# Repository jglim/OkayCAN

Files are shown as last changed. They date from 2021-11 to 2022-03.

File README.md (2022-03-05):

# OkayCAN

*The okayest ESP32-S2 CAN development board*

Expectations shield

OkayCAN board

## Features

- Essentially an ESP32-S2 with a CAN transceiver and supporting components.
- Native USB support, saving on an additional USB-UART chip.
- Designed to fit a commonly available OBD enclosure and its 16-pin connectors.
- Each board should cost about US$10 each when assembling about 10 boards, making it fairly affordable in small runs.
- Easy to assemble/manufacture, as all components are on a single side, and most components are surface mounted.
- Uses a USB-C connector, which is easier to interface when the device is installed in difficult-to-reach places.

### Free

This project is permissively licensed (MIT)

- No restrictions and no royalties on private / commercial use.
- The design files (schematic, board) can be downloaded and modified to fit your own requirements.
- Ready-to-use manufacturing files (gerbers, BOM) are also available. Send it to your preferred fab to have the boards made.
- Please feel free to sell the boards that you have made, even if it is a 1:1 clone. There is no need for attribution too.
- The selected [iso-tp stack](https://github.com/lishen2/isotp-c) from [lishen2](https://github.com/lishen2/) that is included in the examples is also MIT-licensed.

---

## Get an OkayCAN

**Build it yourself**

- PCB: [Gerbers are zipped](https://github.com/jglim/OkayCAN/raw/main/Hardware/V1.1/OkayCAN/gerbers/OkayCAN_fab_gerbers_211101.zip) and ready to be uploaded to your fab
- BOM: Almost every component has a matching LCSC part number, and [the CSV](https://github.com/jglim/OkayCAN/blob/main/Hardware/V1.0/OkayCAN/raster/OkayCAN_BOM.csv) works with their BOM upload feature.
    - The only odd part is the OBD2 header (with case), which has to be sourced from marketplaces like Aliexpress
- Assembly: as most of the parts are surface-mounted, getting a stencil will make the process much quicker.

**Buy one**

I'm not assembling any for sale at this time, though I would love to see it being accessible to more people. If you decide to sell complete boards, please let me know so that I may be able to share about it. Everyone is welcome to create and sell clones/variants of the OkayCAN.

---

## Firmware

**[OkayCAN_GettingStarted](https://github.com/jglim/OkayCAN/tree/main/Firmware/Examples/OkayCAN_GettingStarted)**

Get started quickly with this example, which queries a (MB) ECU for parameters such as VIN, part number, and software versions, then displays it on the serial port.

The example will demonstrate communications with an ECU over UDS (a layer above CAN), as well as usage of the serial port over USB CDC. When working properly, the serial should show an output similar to this:

```
Voltage: 11993 mV
00000BBE TX ISO-TP: 22 F1 8C
00000BC3 RX ISO-TP: 62 F1 8C 33 31 33 31 XX XX XX XX
Received Serial Number: 3131XXXX
Voltage: 11979 mV
00000FA7 TX ISO-TP: 22 F1 90
00000FAC RX ISO-TP: 62 F1 90 57 44 44 32 34 36 32 30 30 31 4A XX XX XX XX XX XX
Received VIN Original: WDD2462001JXXXXXX
Voltage: 12003 mV
00001390 TX ISO-TP: 22 F1 A0
00001394 RX ISO-TP: 62 F1 A0 57 44 44 32 34 36 32 30 30 31 4A XX XX XX XX XX XX
Received VIN Current: WDD2462001JXXXXXX
Voltage: 12003 mV
00001779 TX ISO-TP: 22 F1 21
00001783 RX ISO-TP: 62 F1 21 36 35 31 39 30 34 30 33 30 31 36 35 31 39 30 32 33 31 30 31 36 35 31 39 30 33 31 34 33 31
Received Software block data:
6519040301
6519023101
6519031431
Voltage: 11984 mV
00001B62 TX ISO-TP: 22 F1 00
00001B67 RX ISO-TP: 62 F1 00 02 21 31 01
Received Variant ID: 2131
Voltage: 12003 mV
00001F4B TX ISO-TP: 22 F1 11
00001F50 RX ISO-TP: 62 F1 11 36 35 31 39 30 31 30 36 30 31
Received Part Number: 6519010601
...
```

**[OkayCAN_OBD](https://github.com/jglim/OkayCAN/tree/main/Firmware/Examples/OkayCAN_OBD)**

_UNVERIFIED: No vehicle to test on; tested against a simulated ecu on another esp32. Please let me know if this works! --jg_

Queries an OBD-II compliant ECU for its engine speed, vehicle speed, and throttle position. These parameters are typically supported by most ECUs.

A open Wi-Fi network with the name "OkayCAN-OBD" is also created, and serves a simple web page over http at [192.168.4.1](http://192.168.4.1/) . The page shows real-time results of the OBD queries as JSON if they are available.

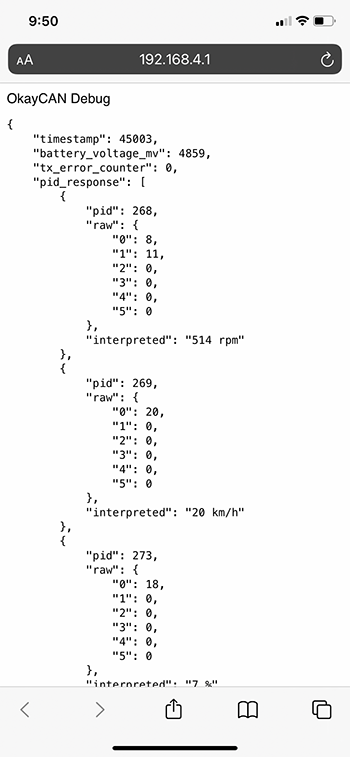
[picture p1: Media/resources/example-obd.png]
OBD Example screenshot


---

## Hardware

⚠️ Warning: components are rated for 12V only! Please do not connect to 24V systems.

### OkayCAN V1.0

*Please use the newer V1.1 as it addresses a board outline issue*

**Schematic [(PDF)](https://github.com/jglim/OkayCAN/blob/main/Hardware/V1.0/OkayCAN/raster/OkayCAN_Schematic.pdf)**

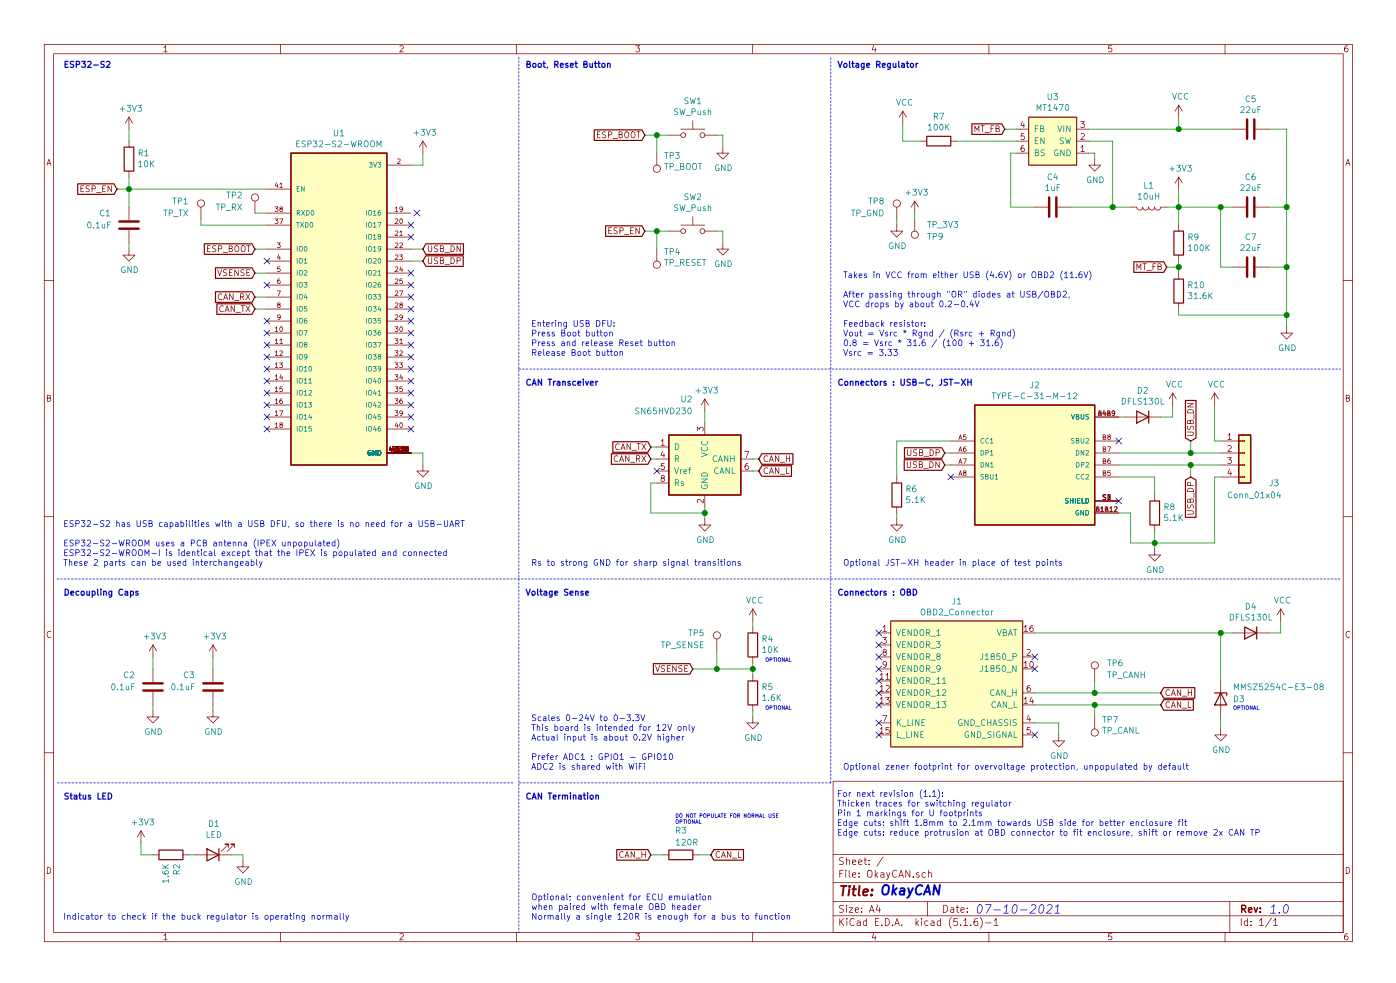
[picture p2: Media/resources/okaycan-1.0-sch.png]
OkayCAN schematic


TL;DR:
**Power**: Vin (USB: 5V, OBD: 12V) with a diode "OR" into a 3.3V buck regulator (MT1470).
**uC**: CAN_TX @ GPIO5, CAN_RX @ GPIO4, VSENSE @ GPIO2 (Divider ratio: Vin-10K,1.6K-GND)
**OBD**: Only CAN TX/RX, VBATT and *chassis* GND are connected. Other pins are NC.

⚠️ The MT1470 regulator only starts operating at 4.5V, which leaves a small margin for the schottky's forward voltage when running off 5V from USB.

ℹ️ The optional 120R CAN resistors should **not** be populated for normal operation as the bus on the vehicle's port normally includes termination resistors.

ℹ️ Test points are available on the back. The ESP32-S2 can also be flashed with an external USB-UART with these test points (like the regular ESP32).

**Board**

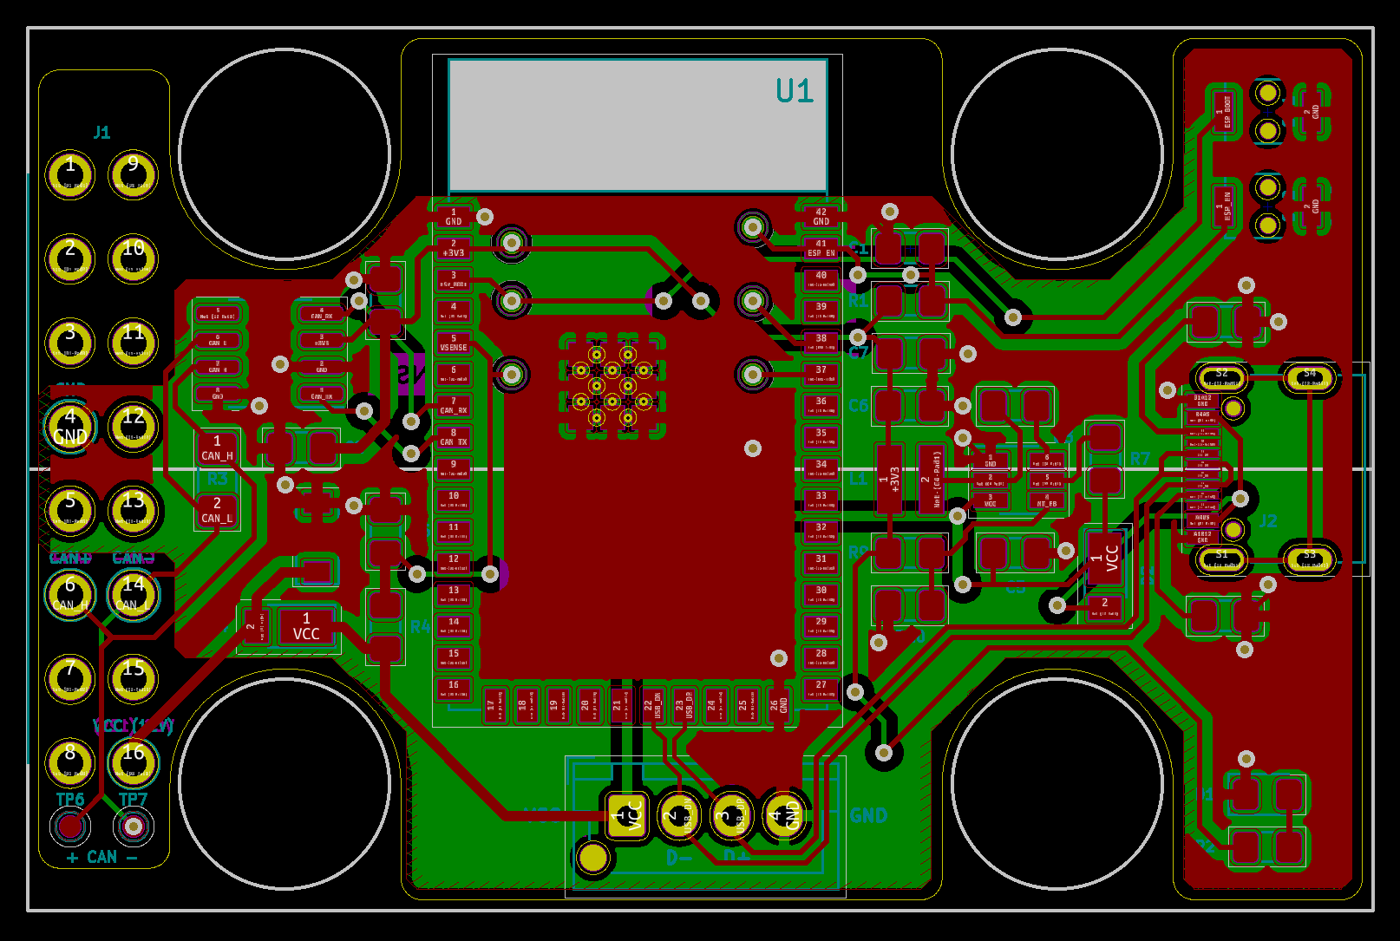
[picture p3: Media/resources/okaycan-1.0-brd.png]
OkayCAN board


ℹ️ V1.0 requires a minor case modification to fit properly, as the OBD connector's sides are too wide. There are two small plastic tabs on the case, near the OBD header which can be safely removed to allow the board to fit properly.

**BOM**

Available [here](https://github.com/jglim/OkayCAN/blob/main/Hardware/V1.0/OkayCAN/raster/OkayCAN_BOM.csv). Budgetary component prices available in [this extended BOM](https://github.com/jglim/OkayCAN/blob/main/Hardware/V1.0/OkayCAN/raster/OkayCAN_Price_Breakdown.csv).

---

### OkayCAN V1.1

*Latest version*

Minor revision to V1.0

- Adjusted board outline to fit the standard cases without modifications
- Added an optional user LED to GPIO16, unpopulated by default
- Minor routing improvements, footprint positions are unchanged and a stencil from V1.0 will still work on this board

---

## DFU

The ESP32-S2 has a USB ROM bootloader which is read-only. This guarantees that a faulty firmware will not brick the device.
OkayCAN includes BOOT and RESET buttons which can be used to bring the device into DFU, to upload a new firmware.

*Enter DFU mode with these steps:*

1. Press BOOT button
2. Press RESET button
3. Release RESET button
4. Release BOOT button

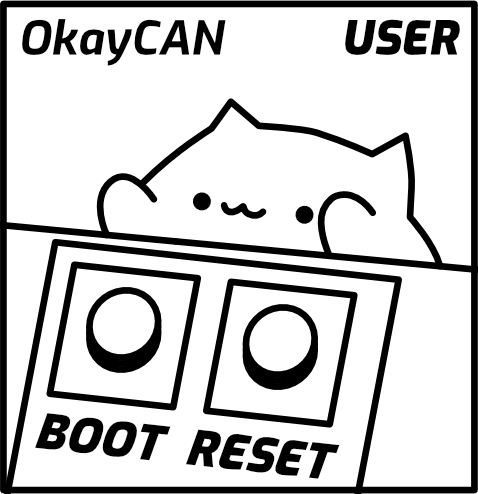
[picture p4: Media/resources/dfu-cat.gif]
Animated DFU instructions


The device can also be put into DFU mode using only the BOOT button. Hold down BOOT while disconnecting and reconnecting the USB cable, then release BOOT.

After flashing the firmware, remember to press RESET once, or reconnect the USB cable to exit DFU and start running your firmware.

---

## Contributing

Please..

- Build cool stuff with the OkayCAN (and let me know if you do, too!).
- Point out and suggest fixes if there are any issues with the hardware design or firmware.
- Add or improve on the existing examples.
- If you fab these boards with a pick-and-place, I would love to hear about your experience.

Need ideas on what to build? Here are some ideas:

- Control an instrument cluster for your racing or truck sim.
- A vehicle communications interface e.g. a J2534 interface.
- Wireless coding/tuning/upgrading via your phone
- Race telemetry/logger with digital gauges

---

## License

MIT

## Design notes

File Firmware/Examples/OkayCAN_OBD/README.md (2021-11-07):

# OkayCAN : OBD

**UNVERIFIED**
_No vehicle to test on; tested against a simulated ecu on another esp32.
Please let me know if this works! --jg_

Queries an OBD-II compliant ECU for its engine speed, vehicle speed, 
and throttle position. These parameters are typically supported by most ECUs.

A open Wi-Fi network with the name "OkayCAN-OBD" is also created, and serves a 
simple web page over http at 192.168.4.1 . The page shows real-time results of the
OBD queries as JSON if they are available.

The contents of the web page can be found in the index.html
Further instructions on editing it can be found in mainpage.h

Assumes that the bus arbitration IDs are 7E0/7E8, running at 500k baud. 
These values can be changed in config.h

This example depends on [ESPAsyncTCP](https://github.com/me-no-dev/ESPAsyncTCP) and [ESPAsyncWebServer](https://github.com/me-no-dev/ESPAsyncWebServer) from [me-no-dev](https://github.com/me-no-dev/).

## Uploading

Enter DFU mode with these steps:

1. Press BOOT button
2. Press RESET button
3. Release RESET button
4. Release BOOT button

When done correctly, a serial port should appear on the connected computer, which can be used for uploading the firmware.
After the upload completes, press and release RESET to begin running the newly flashed firmware.

## Webpage Output

```
OkayCAN Debug
{
    "timestamp": 35530765,
    "battery_voltage_mv": 4783,
    "tx_error_counter": 0,
    "pid_response": [
        {
            "pid": 268,
            "raw": {
                "0": 1,
                "1": 224,
                "2": 0,
                "3": 0,
                "4": 0,
                "5": 0
            },
            "interpreted": "120 rpm"
        },
        {
            "pid": 269,
            "raw": {
                "0": 231,
                "1": 0,
                "2": 0,
                "3": 0,
                "4": 0,
                "5": 0
            },
            "interpreted": "231 km/h"
        },
        {
            "pid": 273,
            "raw": {
                "0": 229,
                "1": 0,
                "2": 0,
                "3": 0,
                "4": 0,
                "5": 0
            },
            "interpreted": "90 %"
        }
    ]
}
```

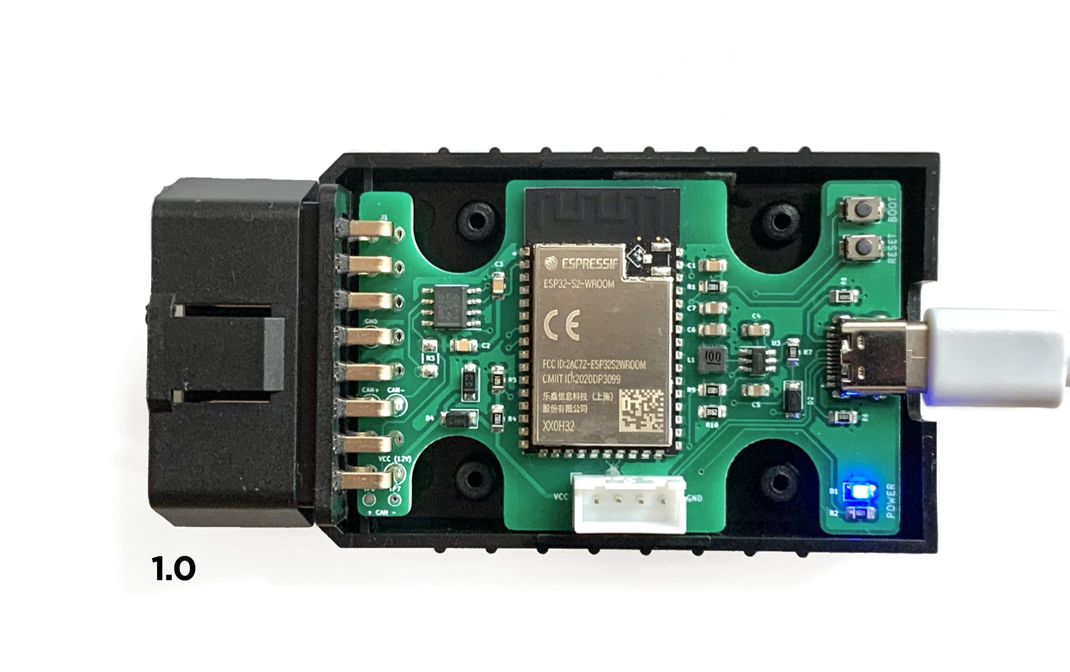
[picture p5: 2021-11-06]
Media/resources/okaycan.jpg

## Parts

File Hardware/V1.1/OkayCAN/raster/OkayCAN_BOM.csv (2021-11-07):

Id | Designator | Package | Quantity | Designation | Supplier and ref
1 | R11,R5,R2 | R_0805_2012Metric_Pad1.15x1.40mm_HandSolder | 3 | 1.6K
2 | D5,D1 | LED_0805_2012Metric_Pad1.15x1.40mm_HandSolder | 2 | LED
3 | G*** | OkayCAN_Silk | 1 | LOGO
4 | kibuzzard-615D3B2E,kibuzzard-615D34D3,kibuzzard-615D3669,kibuzzard-615D361C,kibuzzard-615D34DF,kibuzzard-615D34D3,kibuzzard-615D34C8,kibuzzard-615D34B9,kibuzzard-615D34B0,kibuzzard-615D34A6 | label | 10 | G***
5 | TP9 | TestPoint_Pad_D1.0mm | 1 | TP_3V3
6 | TP8 | TestPoint_Pad_D1.0mm | 1 | TP_GND
7 | TP4 | TestPoint_Pad_D1.0mm | 1 | TP_RESET
8 | TP3 | TestPoint_Pad_D1.0mm | 1 | TP_BOOT
9 | TP7 | TestPoint_Pad_D1.0mm | 1 | TP_CANL
10 | TP6 | TestPoint_Pad_D1.0mm | 1 | TP_CANH
11 | TP5 | TestPoint_Pad_D1.0mm | 1 | TP_SENSE
12 | TP2 | TestPoint_Pad_D1.0mm | 1 | TP_RX
13 | TP1 | TestPoint_Pad_D1.0mm | 1 | TP_TX
14 | U3 | SOT-23-6_Handsoldering | 1 | MT1470
15 | U2 | SOIC-8_3.9x4.9mm_P1.27mm | 1 | SN65HVD230
16 | U1 | XCVR_ESP32-S2-WROOM | 1 | ESP32-S2-WROOM
17 | SW2,SW1 | HRO-K2-1807 | 2 | SW_Push
18 | R10 | R_0805_2012Metric_Pad1.15x1.40mm_HandSolder | 1 | 31.6K
19 | R9,R7 | R_0805_2012Metric_Pad1.15x1.40mm_HandSolder | 2 | 100K
20 | R8,R6 | R_0805_2012Metric_Pad1.15x1.40mm_HandSolder | 2 | 5.1K
21 | R4,R1 | R_0805_2012Metric_Pad1.15x1.40mm_HandSolder | 2 | 10K
22 | R3 | R_1206_3216Metric_Pad1.42x1.75mm_HandSolder | 1 | 120R
23 | L1 | CHILSIN-LVF303012 | 1 | 10uH
24 | J3 | JST_XH_B4B-XH-AM_1x04_P2.50mm_Vertical | 1 | Conn_01x04
25 | J2 | HRO_TYPE-C-31-M-12 | 1 | TYPE-C-31-M-12
26 | J1 | OBD-Male | 1 | OBD2_Connector
27 | D4,D2 | D_PowerDI-123 | 2 | DFLS130L
28 | D3 | D_SOD-123 | 1 | MMSZ5254C-E3-08
29 | C7,C6,C5 | C_0805_2012Metric_Pad1.15x1.40mm_HandSolder | 3 | 22uF
30 | C4 | C_0805_2012Metric_Pad1.15x1.40mm_HandSolder | 1 | 1uF
31 | C3,C2,C1 | C_0805_2012Metric_Pad1.15x1.40mm_HandSolder | 3 | 0.1uF

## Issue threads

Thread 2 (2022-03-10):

WebBLE

brandonros, 2022-03-10:
https://github.com/bri3d/esp32-isotp-ble-bridge

You should make it compatible with this firmware.

brandonros, 2022-03-10:
You only support WiFi, forogt.

jglim, 2022-03-11:
Yes, unfortunately the esp32-s2 does not appear to be capable of BLE too.

https://www.espressif.com/sites/default/files/documentation/esp32-s2_datasheet_en.pdf
https://www.adafruit.com/product/4653

_".. Also, thee is no Bluetooth support. However, we are super excited about the ESP32-S2's native USB which unlocks a lot of capabilities for advanced interfacing!"_

brandonros, 2022-03-11:
Which ESP32 chip has BLE?

brandonros, 2022-03-11:
which does macchina a0 use? you should update your schematic to use that. bigger market for BLE than USB in my opinion.

i’m not a fan of flashing cars wirelessly on a $1 piece of silicon but hey…

jglim, 2022-03-11:
Looks like a regular esp32 (ESP32-WROVER-E)
https://github.com/macchina/a0-hardware/blob/master/A0%20Schematic%20Production.pdf

I'll keep your feedback in mind about the esp32 and BLE if the board is redesigned.

Closed 2022-03-10.

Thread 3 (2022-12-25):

Send consecutive frame

Liu-jingyu-CN, 2022-12-25:
Thanks a lot for this project, I have successfully try to read gateway.
But when I need to do more in-depth operations, I need to Send consecutive frame.
Perform other service operations by informing the gateway diagnostic instrument to access.
For example, use 2E service to send a piece of RAW CAN data to modify vehicle data.
Is it possible to add a demo that Send consecutive frame ？

00007937 TX ISO-TP: 22 F1 97
0000794B RX ISO-TP: 62 F1 97 47 57 20 4D 51 42 20 54 54 33 20 20 20
Received VW System Name: GW MQB TT3
00007D20 TX ISO-TP: 22 F1 91
00007D3D RX ISO-TP: 62 F1 91 38 53 30 39 30 37 34 36 38 46 20
Received VW ECU Hardware Number: 8S0907468F
00008109 TX ISO-TP: 22 F1 87
00008125 RX ISO-TP: 62 F1 87 38 53 30 39 30 37 34 36 38 4E 20
Received VW_Spare Part Number: 8S0907468N
000084F2 TX ISO-TP: 22 F1 A3
000084F9 RX ISO-TP: 62 F1 A3 30 32 34
Received Hardware Version Number: 024
000088DB TX ISO-TP: 22 F1 89
000088E1 RX ISO-TP: 62 F1 89 30 35 30 32
Received Software Version Number: 0502
00008CC4 TX ISO-TP: 22 F1 9E
00008CE7 RX ISO-TP: 62 F1 9E 45 56 5F 47 61 74 65 77 43 6F 6E 74 69 41 55 33 33 58 00
Received ASAM ODX File Identifier: EV_GatewContiAU33X
000090AD TX ISO-TP: 22 F1 A2
000090BB RX ISO-TP: 62 F1 A2 30 31 33 30 32 36
Received ASAM ODX File Version: 013026
00009496 TX ISO-TP: 22 06 00
000094C1 RX ISO-TP: 62 06 00 03 01 00 04 3F 08 59 00 5B 00 00 4A 1A 0B 00 00 00 01 01 00 00 00 00 00 00 00 00 00 00 00
Received VW Coding Value: 03 01 00 04 3F 08 59 00 5B 00 00 4A 1A 0B 00 00 00 01 01 00 00 00 00 00 00 00 00 00 00 00
0000987F TX ISO-TP: 22 04 90
000099FD RX ISO-TP: 62 04 90 21 2D 2D 2D 2D 2D 2D 2D 2D 2D 2D 2D 2D 2D 3A 2D 2D 2A 2D 2D 2E 2D 2A 2D 2D 2A 2D 2D 2D 2D 2D 2A 2A 2A 1A 2D 2D 2D 2D 2D 2D 2D 2D 2D 2D 2D 2D 2D 3A 2D 2D 2A 2D 2D 2E 2D 2A 2D 2D 2A 2A 1A 2D 2D 2D 2D 2D 2D 2D 2D 2D 2D 2D 2D 2D 3A 2D 2D 2A 2D 2D 2E 2D 2A 2D 2D 2A 2A 21 2D 2D 2D 2D 2D 2D 2D 2D 2D 2D 2D 2D 2D 3A 2D 2D 2A 2D 2D 2E 2D 2A 2D 2D 2A 2D 2D 2D 2D 2D 2A 2A 2A 1A 2D 2D 2D 2D 2D 2D 2D 2D 2D 2D 2D 2D 2D 3A 2D 2D 2A 2D 2D 2E 2D 2A 2D 2D 2A 2A 1A 2D 2D 2D 2D 2D 2D 2D 2D 2D 2D 2D 2D 2D 3A 2D 2D 2A 2D 2D 2E 2D 2A 2D 2D 2A 2A 21 2D 2D 2D 2D 2D 2D 2D 2D 2D 2D 2D 2D 2D 3A 2D 2D 2A 2D 2D 2E 2D 2A 2D 2D 2A 2D 2D 2D 2D 2D 2A 2A 2A 1A 2D 2D 2D 2D 2D 2D 2D 2D 2D 2D 2D 2D 2D 3A 2D 2D 2A 2D 2D 2E 2D 2A 2D 2D 2A 2A 1A 2D 2D 2D 2D 2D 2D 2D 2D 2D 2D 2D 2D 2D 3A 2D 2D 2A 2D 2D 2E 2D 2A 2D 2D 2A 2A
Received Battery Historical Data:
!-------------:--*--.-*--*-----***␚-------------:--*--.-*--**␚-------------:--*--.-*--**
!-------------:--*--.-*--*-----***␚-------------:--*--.-*--**␚-------------:--*--.-*--**
!-------------:--*--.-*--*-----***␚-------------:--*--.-*--**␚-------------:--*--.-*--**
00009C68 TX ISO-TP: 22 2A 26
00009C9B RX ISO-TP: 62 2A 26 01 00 00 00 00 00 00 00 00 00 00 00 00 00 00 00 00 00 00 00 00 00 00 00 00 00 00 00 00 00 00 00
Gateway Component List allocation: 01 00 00 00 00 00 00 00 00 00 00 00 00 00 00 00 00 00 00 00 00 00 00 00 00 00 00 00 00 00 00 00

jglim, 2022-12-28:
Hello,

Thanks for trying out the project. The included examples are supported by https://github.com/lishen2/isotp-c/ , which should support automatic frame segmentation.

In the below example, the buffer in `transport_tx_buffer` can be filled with more content (remember to change `content_length` too), and it should be automatically be broken into first/consecutive frames during transmission.

https://github.com/jglim/OkayCAN/blob/24859feef76e1b3540869f00db903b38f7d8b79d/Firmware/Examples/OkayCAN_GettingStarted/src/main.cpp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

Closed 2022-12-29.

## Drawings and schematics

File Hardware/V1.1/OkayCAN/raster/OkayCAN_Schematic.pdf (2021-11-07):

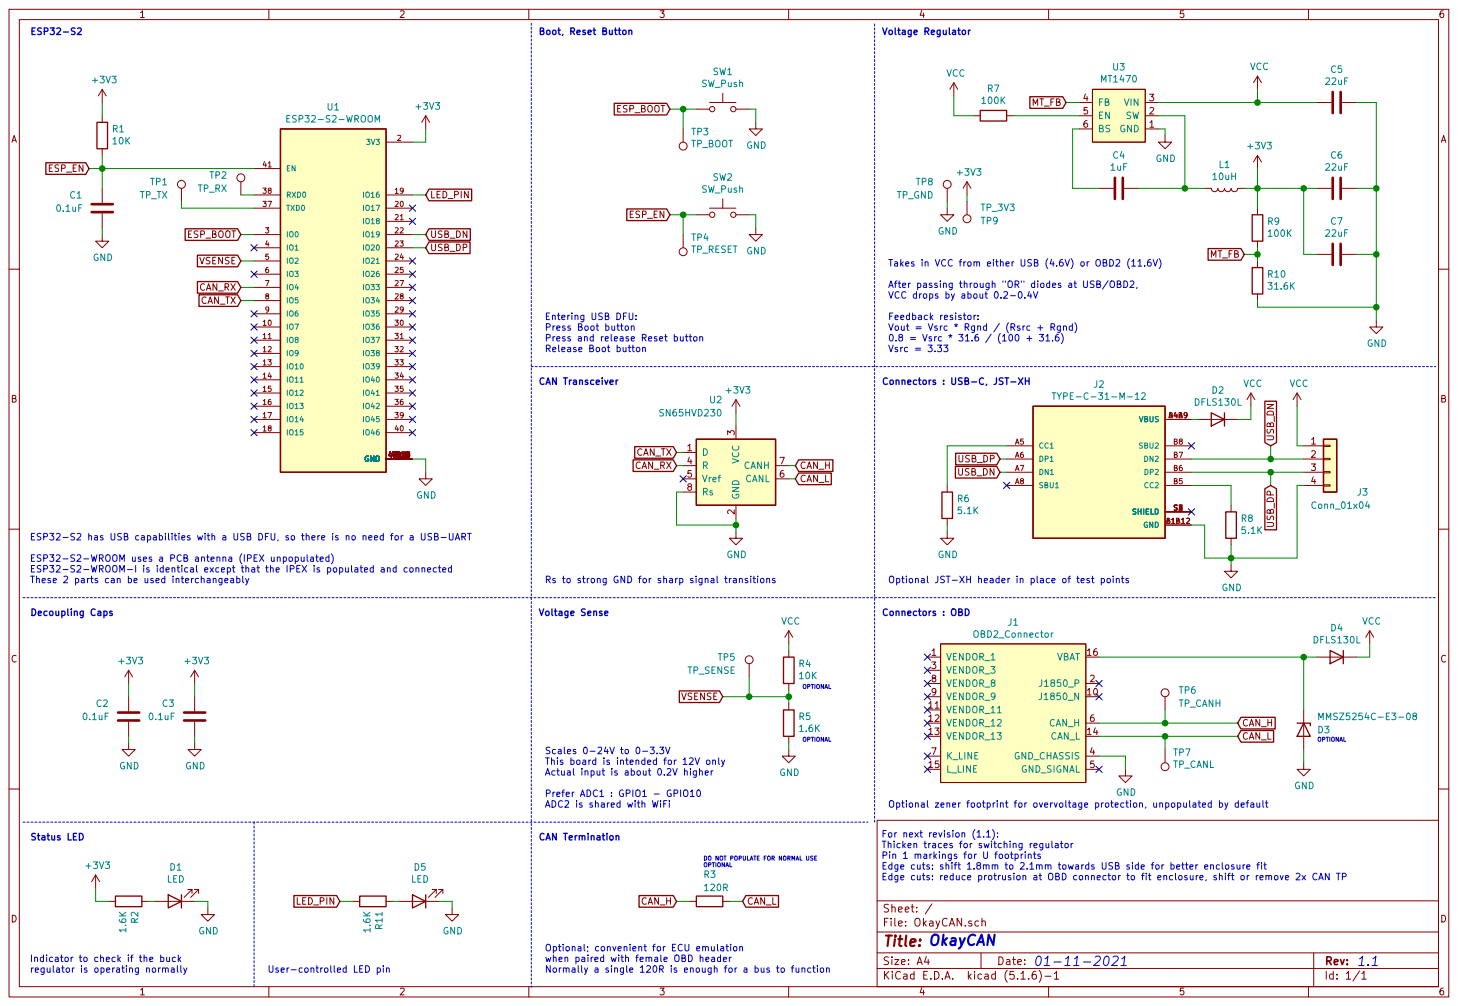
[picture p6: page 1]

Boot, Reset Button Entering USB DFU: Press Boot button Press and release Reset button Release Boot button Decoupling Caps

Takes in VCC from either USB (4.6V) or OBD2 (11.6V)

After passing through "OR" diodes at USB/OBD2,
VCC drops by about 0.2-0.4V

Feedback resistor: Vout = Vsrc * Rgnd / (Rsrc + Rgnd)

Connectors : USB-C, JST-XH

ESP32-S2 has USB capabilities with a USB DFU, so there is no need for a USB-UART

ESP32-S2-WROOM uses a PCB antenna (IPEX unpopulated)
ESP32-S2-WROOM-I is identical except that the IPEX is populated and connected
These 2 parts can be used interchangeably

Voltage Sense Scales 0-24V to 0-3.3V

This board is intended for 12V only
Actual input is about 0.2V higher Prefer ADC1 : GPIO1 - GPIO10 ADC2 is shared with WiFi

Thicken traces for switching regulator
Pin 1 markings for U footprints
Edge cuts: shift 1.8mm to 2.1mm towards USB side for better enclosure fit
Edge cuts: reduce protrusion at OBD connector to fit enclosure, shift or remove 2x CAN TP

Indicator to check if the buck regulator is operating normally

when paired with female OBD header
Normally a single 120R is enough for a bus to function

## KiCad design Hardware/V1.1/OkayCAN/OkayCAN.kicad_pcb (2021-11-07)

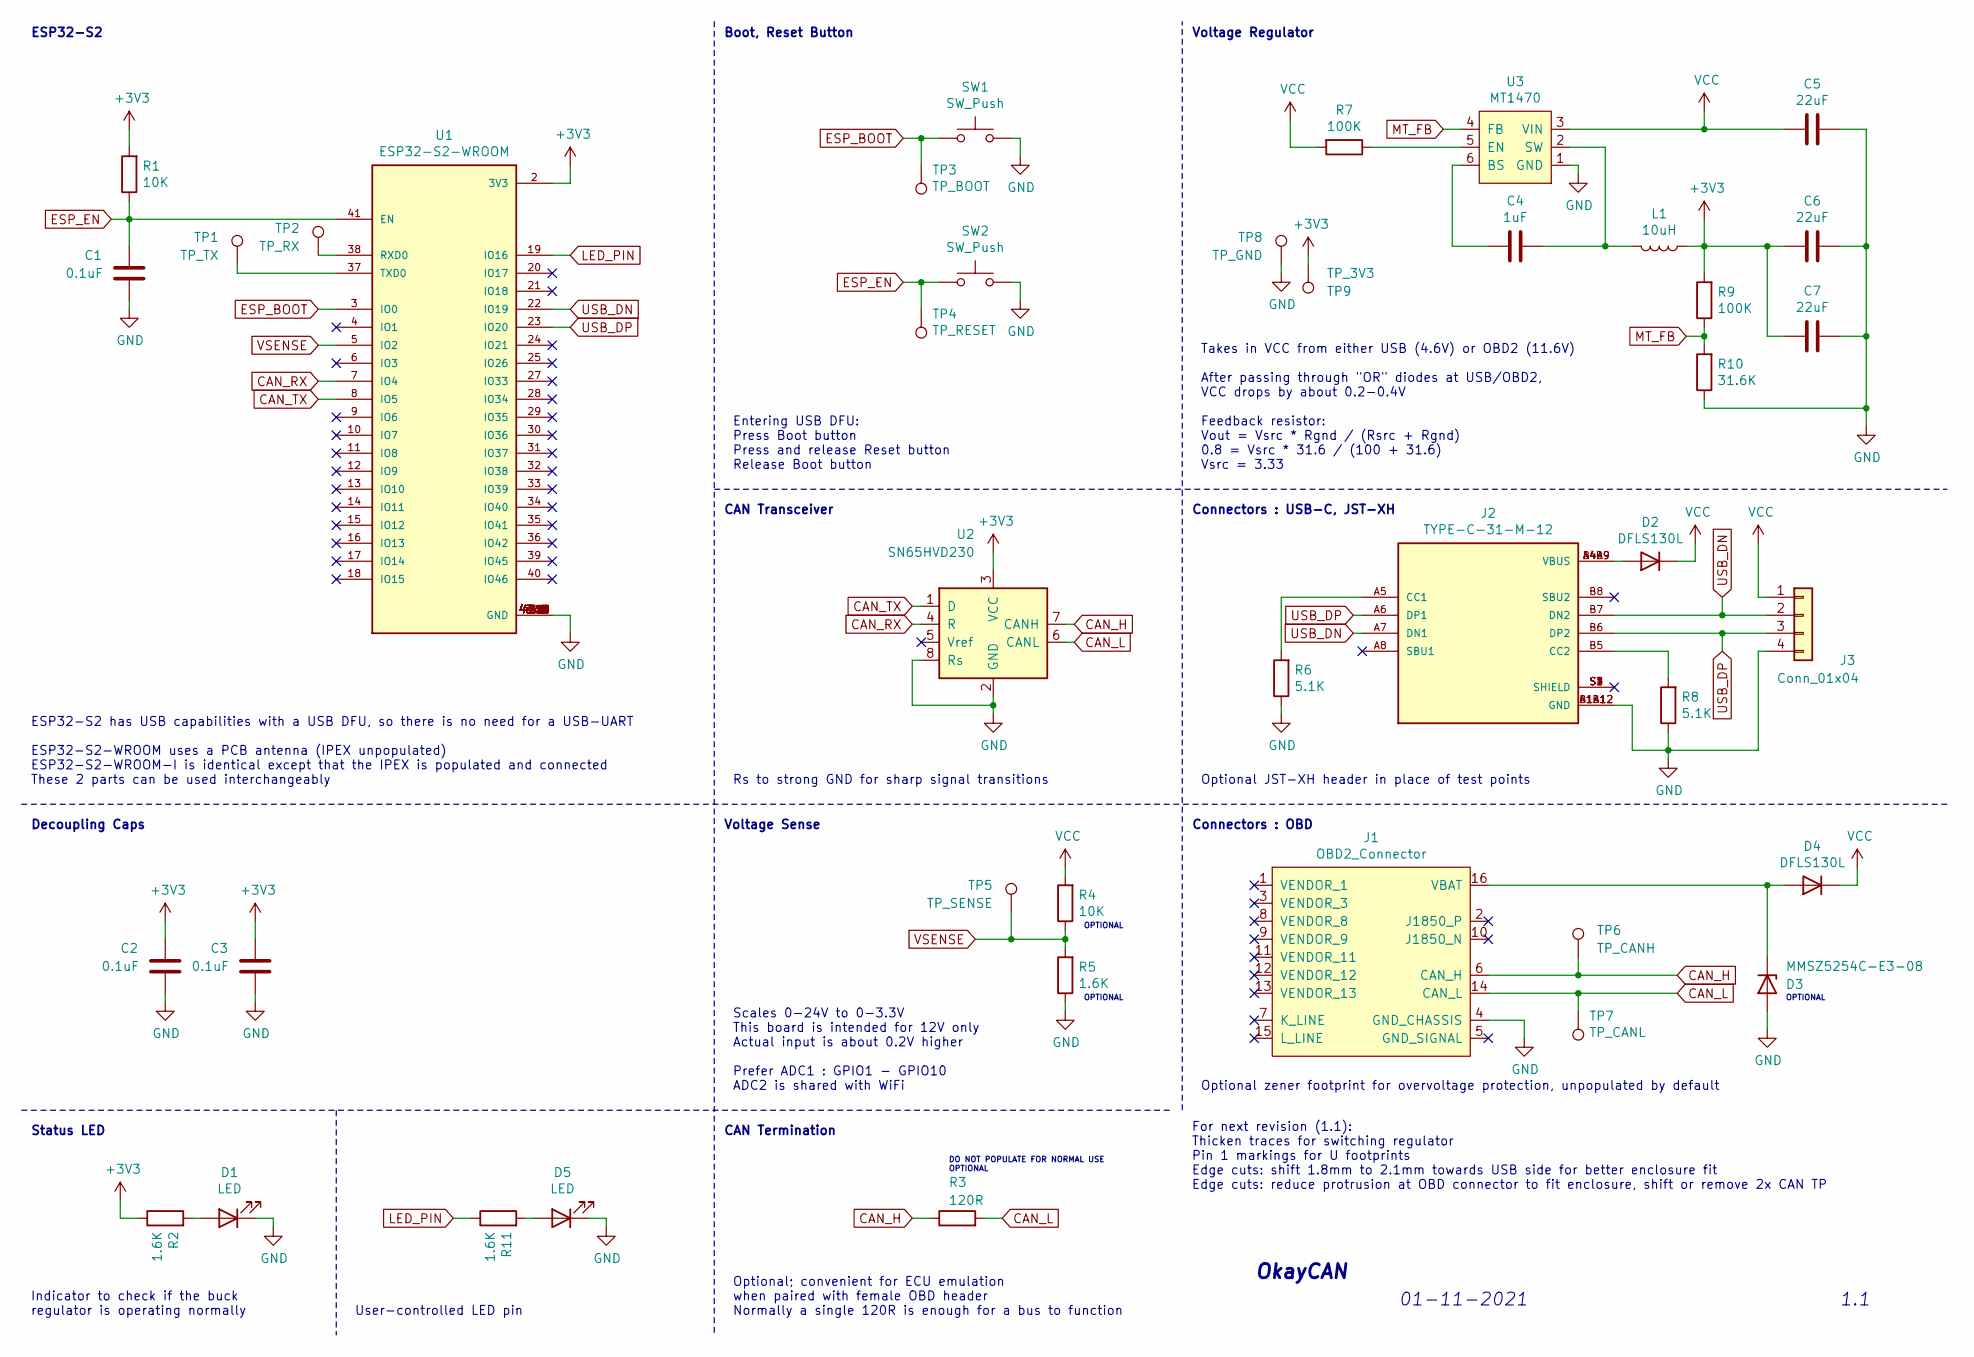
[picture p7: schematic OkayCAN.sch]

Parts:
C1, C2, C3: 0.1uF; C_0805_2012Metric_Pad1.15x1.40mm_HandSolder; LCSC C138340
C4: 1uF; C_0805_2012Metric_Pad1.15x1.40mm_HandSolder; LCSC C28323
C5, C6, C7: 22uF; C_0805_2012Metric_Pad1.15x1.40mm_HandSolder; LCSC C45783
D1, D5: LED; LED_0805_2012Metric_Pad1.15x1.40mm_HandSolder; LCSC C84259
D2, D4: DFLS130L; D_PowerDI-123; LCSC C110493
D3: MMSZ5254C-E3-08; D_SOD-123; LCSC C241953
J1: OBD2_Connector; OBD-Male
J2: TYPE-C-31-M-12; HRO_TYPE-C-31-M-12; PARTREV A; LCSC C165948
J3: Conn_01x04; JST_XH_B4B-XH-AM_1x04_P2.50mm_Vertical; LCSC C161871
L1: 10uH; CHILSIN-LVF303012; LCSC C142153
R1, R4: 10K; R_0805_2012Metric_Pad1.15x1.40mm_HandSolder; LCSC C84376
R2, R5, R11: 1.6K; R_0805_2012Metric_Pad1.15x1.40mm_HandSolder; LCSC C17394
R3: 120R; R_1206_3216Metric_Pad1.42x1.75mm_HandSolder; LCSC C175512
R6, R8: 5.1K; R_0805_2012Metric_Pad1.15x1.40mm_HandSolder; LCSC C336831
R7, R9: 100K; R_0805_2012Metric_Pad1.15x1.40mm_HandSolder; LCSC C96346
R10: 31.6K; R_0805_2012Metric_Pad1.15x1.40mm_HandSolder; LCSC C228743
SW1, SW2: SW_Push; HRO-K2-1807; LCSC C502307
TP1: TP_TX; TestPoint_Pad_D1.0mm
TP2: TP_RX; TestPoint_Pad_D1.0mm
TP3: TP_BOOT; TestPoint_Pad_D1.0mm
TP4: TP_RESET; TestPoint_Pad_D1.0mm
TP5: TP_SENSE; TestPoint_Pad_D1.0mm
TP6: TP_CANH; TestPoint_Pad_D1.0mm
TP7: TP_CANL; TestPoint_Pad_D1.0mm
TP8: TP_GND; TestPoint_Pad_D1.0mm
TP9: TP_3V3; TestPoint_Pad_D1.0mm
U1: ESP32-S2-WROOM; XCVR_ESP32-S2-WROOM; PARTREV V1.0; LCSC C967025
U2: SN65HVD230; SOIC-8_3.9x4.9mm_P1.27mm; LCSC C12084
U3: MT1470; SOT-23-6_Handsoldering; LCSC C181781

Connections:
+3V3: C2.1, C3.1, C6.2, C7.2, L1.1, R1.2, R2.1, R9.2, TP9.1, U1.2 (3V3), U2.3 (VCC)
CAN_H: J1.6 (CAN_H), R3.1, TP6.1, U2.7 (CANH)
CAN_L: J1.14 (CAN_L), R3.2, TP7.1, U2.6 (CANL)
CAN_RX: U1.7 (IO4), U2.4 (R)
CAN_TX: U1.8 (IO5), U2.1 (D)
ESP_BOOT: SW1.1, TP3.1, U1.3 (IO0)
ESP_EN: C1.1, R1.1, SW2.1, TP4.1, U1.41 (EN)
GND: C1.2, C2.2, C3.2, C5.1, C6.1, C7.1, D1.1 (K), D3.2 (A), D5.1 (K), J1.4 (GND_CHASSIS), J2.A1B12 (GND), J2.B1A12 (GND), J3.4, R5.1, R6.1, R8.1, R10.1, SW1.2, SW2.2, TP8.1, U1.1 (GND), U1.26 (GND), U1.42 (GND), U1.43.1 (GND), U1.43.2 (GND), U1.43.3 (GND), U1.43.4 (GND), U1.43.5 (GND), U1.43.6 (GND), U1.43.7 (GND), U1.43.8 (GND), U1.43.9 (GND), U1.43.10 (GND), U1.43.11 (GND), U1.43.12 (GND), U1.43.13 (GND), U1.43.14 (GND), U1.43.15 (GND), U1.43.16 (GND), U1.43.17 (GND), U1.43.18 (GND), U1.43.19 (GND), U1.43.20 (GND), U1.43.21 (GND), U2.2 (GND), U2.8 (Rs), U3.1 (GND)
LED_PIN: R11.1, U1.19 (IO16)
MT_FB: R9.1, R10.2, U3.4 (FB)
unnamed: C4.1, L1.2, U3.2 (SW)
unnamed: C4.2, U3.6 (BS)
unnamed: D1.2 (A), R2.2
unnamed: D2.2 (A), J2.A4B9 (VBUS), J2.B4A9 (VBUS)
unnamed: D3.1 (K), D4.2 (A), J1.16 (VBAT)
unnamed: D5.2 (A), R11.2
unnamed: J2.A5 (CC1), R6.2
unnamed: J2.B5 (CC2), R8.2
unnamed: J2.S1 (SHIELD), J2.S2 (SHIELD), J2.S3 (SHIELD), J2.S4 (SHIELD)
unnamed: R7.1, U3.5 (EN)
unnamed: TP1.1, U1.37 (TXD0)
unnamed: TP2.1, U1.38 (RXD0)
USB_DN: J2.A7 (DN1), J2.B7 (DN2), J3.2, U1.22 (IO19)
USB_DP: J2.A6 (DP1), J2.B6 (DP2), J3.3, U1.23 (IO20)
VCC: C5.2, D2.1 (K), D4.1 (K), J3.1, R4.2, R7.2, U3.3 (VIN)
VSENSE: R4.1, R5.2, TP5.1, U1.5 (IO2)

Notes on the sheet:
Takes in VCC from either USB (4.6V) or OBD2 (11.6V) After passing through "OR" diodes at USB/OBD2, VCC drops by about 0.2-0.4V Feedback resistor: Vout = Vsrc * Rgnd / (Rsrc + Rgnd) 0.8 = Vsrc * 31.6 / (100 + 31.6) Vsrc = 3.33
Voltage Regulator
Connectors : USB-C, JST-XH
ESP32-S2
Boot, Reset Button
Voltage Sense
Scales 0-24V to 0-3.3V This board is intended for 12V only Actual input is about 0.2V higher Prefer ADC1 : GPIO1 - GPIO10 ADC2 is shared with WiFi
CAN Transceiver
Optional zener footprint for overvoltage protection, unpopulated by default
Optional JST-XH header in place of test points
Connectors : OBD
Decoupling Caps
Rs to strong GND for sharp signal transitions
Entering USB DFU: Press Boot button Press and release Reset button Release Boot button
CAN Termination
Optional; convenient for ECU emulation when paired with female OBD header Normally a single 120R is enough for a bus to function
OPTIONAL
Status LED
Indicator to check if the buck regulator is operating normally
ESP32-S2 has USB capabilities with a USB DFU, so there is no need for a USB-UART ESP32-S2-WROOM uses a PCB antenna (IPEX unpopulated) ESP32-S2-WROOM-I is identical except that the IPEX is populated and connected These 2 parts can be used interchangeably
For next revision (1.1): Thicken traces for switching regulator Pin 1 markings for U footprints Edge cuts: shift 1.8mm to 2.1mm towards USB side for better enclosure fit Edge cuts: reduce protrusion at OBD connector to fit enclosure, shift or remove 2x CAN TP
DO NOT POPULATE FOR NORMAL USE
OkayCAN
1.1
01-11-2021
User-controlled LED pin

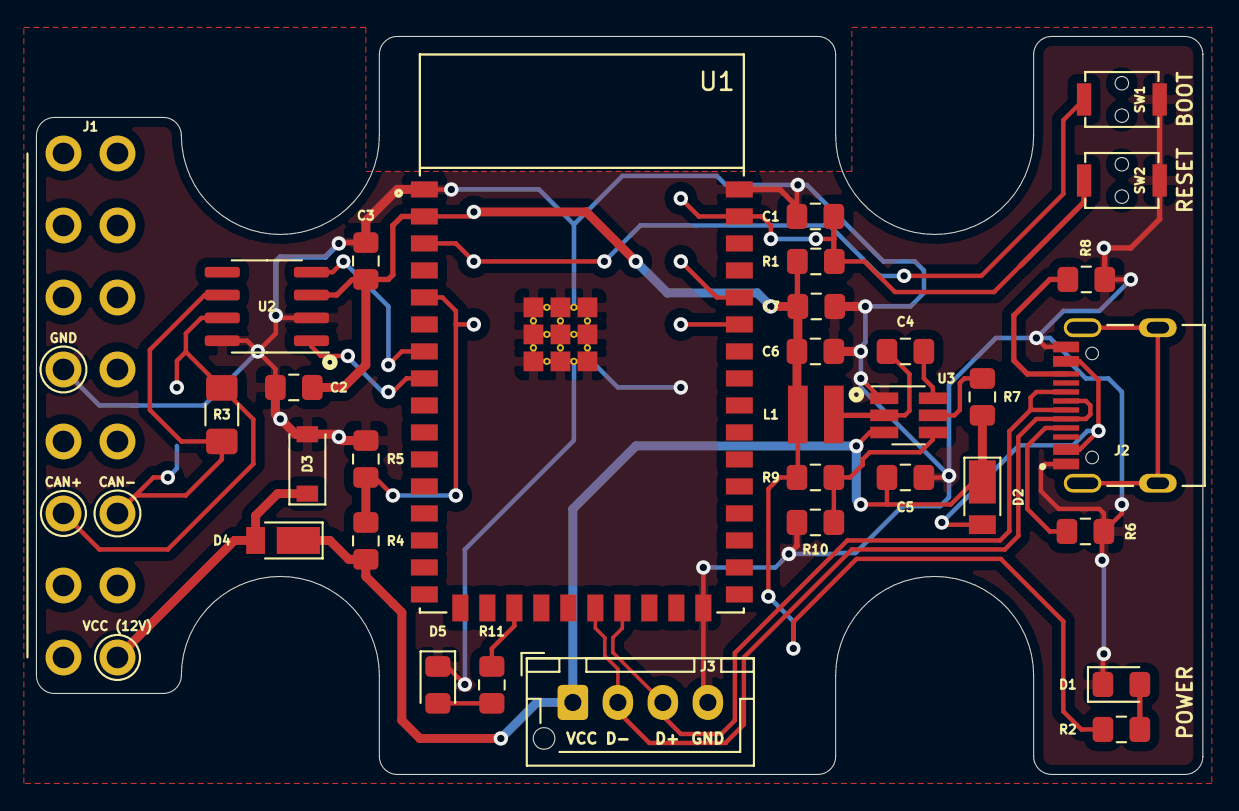
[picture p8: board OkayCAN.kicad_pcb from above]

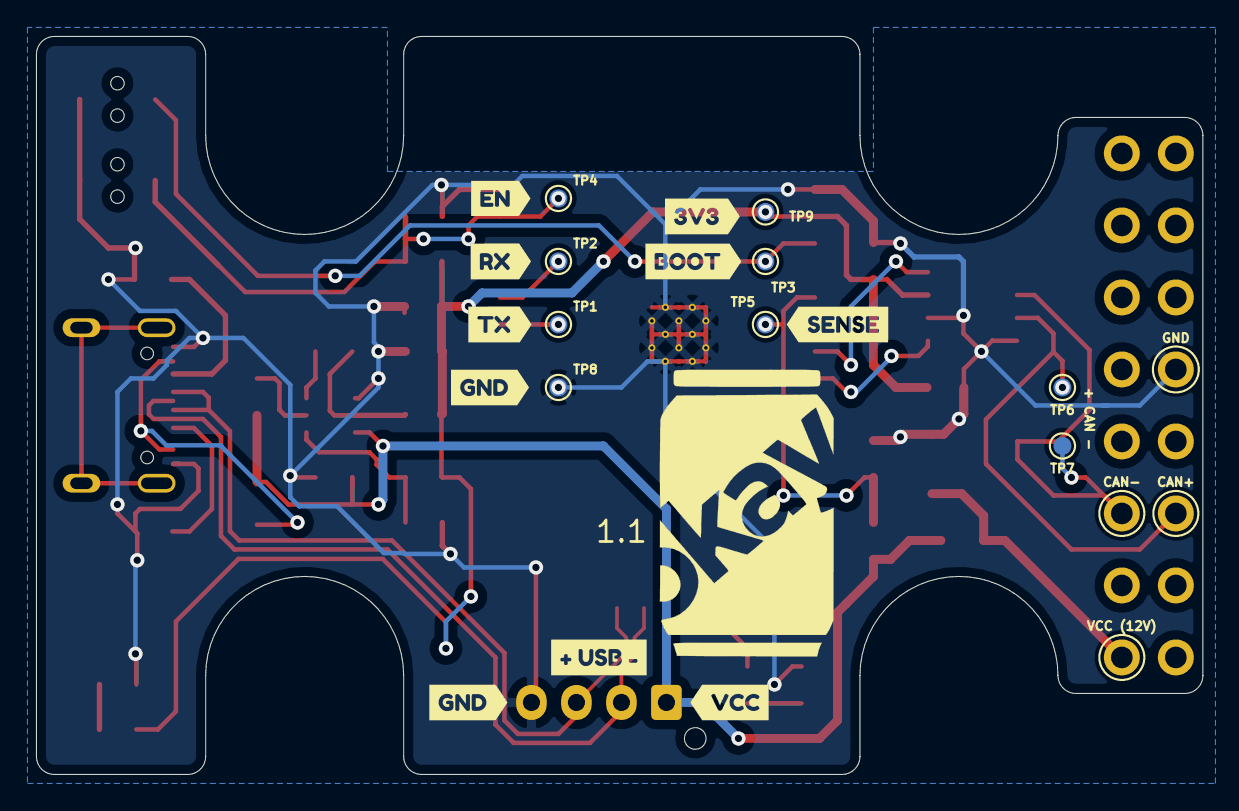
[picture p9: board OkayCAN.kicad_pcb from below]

Board: 2 copper layers, 64.8 x 41.0 mm, 51 parts (19 on the bottom side), 26 nets.

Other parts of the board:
kibuzzard-615D3B2E, kibuzzard-615D34A6, kibuzzard-615D34B0, kibuzzard-615D34B9, kibuzzard-615D34C8, kibuzzard-615D34D3, kibuzzard-615D34D3#2, kibuzzard-615D34DF, kibuzzard-615D361C, kibuzzard-615D3669: G***; label

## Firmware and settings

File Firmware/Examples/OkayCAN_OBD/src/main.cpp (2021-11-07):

/*
OkayCAN : OBD

[UNVERIFIED] 
No vehicle to test on; tested against a simulated ecu on another esp32.
Please let me know if this works! --jg

Queries an OBD-II compliant ECU for its engine speed, vehicle speed, 
and throttle position. These parameters are typically supported by most ECUs.

A open Wi-Fi network with the name "OkayCAN-OBD" is also created, and serves a 
simple web page over http at 192.168.4.1 . The page shows real-time results of the
OBD queries as JSON if they are available.

The contents of the web page can be found in the index.html
Further instructions on editing it can be found in mainpage.h

*/

#include <Arduino.h>

// esp32-s2 has native USB, so we can run our serial through USB-CDC
#include "usbserial/usbserial.h"

// simplified wrapper to work with iso-tp, allows easy switching between CAN and ISO-TP
#include "transport/transport.h"

// global configuration for pin definitions and CAN/ISO-TP parameters
#include "config.h"

// wifi, dns, http
#include <DNSServer.h>
#include <WiFi.h>
#include <AsyncTCP.h>
#include <ESPAsyncWebServer.h>
#include "mainpage.h"

// OBD-II PIDs as defined here: https://en.wikipedia.org/wiki/OBD-II_PIDs
#define SUPPORTED_PIDS_1 (0x0100)
#define ENGINE_SPEED (0x010C)
#define VEHICLE_SPEED (0x010D)
#define THROTTLE_POSITION (0x0111)
#define RUNTIME_SINCE_START (0x011F)
#define OBD_COMPLIANCE (0x011C)

// parameters that we would like to request from the ECU
uint16_t parameters_to_read[] = {
	ENGINE_SPEED,
	VEHICLE_SPEED,
	THROTTLE_POSITION,
};

#define PARAMETER_COUNT (sizeof(parameters_to_read) / sizeof(uint16_t))

#pragma pack(push, 1)
typedef struct OBD_RESULT
{
	uint64_t MSG_TIMESTAMP;
	uint32_t VBATT_MV;
	uint32_t TX_ERROR_COUNTER;
	uint64_t PID_RESPONSE[PARAMETER_COUNT];
} _OBD_RESULT;
#pragma pack(pop)

// these store the raw results for the queried PIDs; interpretation should be done in the browser
OBD_RESULT obd_result;

// hex-string representation of obd_result. 
// hex takes up twice as much space, and one byte is added for the null terminator.
uint8_t result_buffer_text[sizeof(OBD_RESULT) * 2 + 1] = {};

// keeps track of which requests we are issuing
int parameter_request_index = 0;

// millisecond timestamp for "nonblocking" delay
ulong last_query_ms = 0;

// dns & web server
DNSServer dns_server;
AsyncWebServer http_server(80);

// reads the incoming voltage from the vehicle/OBD supply if it is available, or the USB voltage
int read_vcc_mv()
{
	// there are 2 identical schottky "ORing"/backfeed protection diodes on the okaycan board
	// the input voltage will therefore drop by approx 0.2V, depending on the load
	int adcReading = analogReadMilliVolts(GPIO_VSENSE) + 0.2;
	// sense resistors are 10K / 1.6K
	return (int)(adcReading * 4.75);
}

// called when a valid iso-tp message is received
void receive_handler_isotp(int sender_id, uint8_t *payload, int content_length)
{
	if (content_length >= 2)
	{
		uint16_t obd_pid_identifier = ((payload[0] - 0x40) << 8) | payload[1];
		for (int i = 0; i < PARAMETER_COUNT; i++)
		{
			// if it's a response to a pid that we sent, store it in our result buffer
			if (parameters_to_read[i] == obd_pid_identifier)
			{
				// expecting single-frame responses only, any excess will be truncated
				memcpy(&obd_result.PID_RESPONSE[i], payload, 8);
				break;
			}
		}
	}
}

// sends a OBD PID read request
void send_read_query(uint16_t pid)
{
	int content_length = 2;
	transport_tx_buffer[0] = (pid >> 8) & 0xFF;
	transport_tx_buffer[1] = (pid & 0xFF);

	// transmits the ISO-TP message
	if (send(transport_tx_buffer, content_length))
	{
		// transmit completed without issues
	}
	else
	{
		// transmit failed
		USBSerial.println("Send error");
		obd_result.TX_ERROR_COUNTER++;
	}
}

// handlers for http events
void setup_http()
{
	// base page
	http_server.on("/", HTTP_GET, [](AsyncWebServerRequest *request)
				   { request->send_P(200, "text/html", mainpage_p); });

	// obd endpoint
	http_server.on("/poll-ep", HTTP_POST, [](AsyncWebServerRequest *request)
				   { request->send(200, "text/plain", reinterpret_cast<char *>(result_buffer_text)); });

	http_server.begin();
}

// zeroes out the memory for the buffer that stores the pid responses
void zero_pid_buffer()
{
	for (int i = 0; i < PARAMETER_COUNT; i++)
	{
		obd_result.PID_RESPONSE[i] = (uint64_t)0;
	}
}

// runs once when the microcontroller starts
void setup()
{
	// activate the virtual usb (CDC) port
	configure_usb_serial();

	// set the voltage sensing pin as an input
	pinMode(GPIO_VSENSE, INPUT);

	// clear the pid result buffer
	zero_pid_buffer();

	// configure CAN and ISO-TP
	setup_transport(CAN_REQUEST_ID, CAN_RESPONSE_ID, CAN_DATA_RATE);

	// set the operating mode as ISO-TP
	set_transport_mode(MODE_ISOTP);

	// assign receive_handler to be called whenever a valid ISO-TP message is available
	register_receive_handler(receive_handler_isotp);

	// configure networking and http server
	WiFi.softAP("OkayCAN-OBD");
	dns_server.start(53, "*", WiFi.softAPIP());
	setup_http();
}

// converts a nibble into its char-representation, and stores it into *dest
void write_nibble(uint8_t *dest, uint8_t nibble)
{
	*dest = 0x30 + nibble;
	if (*dest > 0x39)
	{
		*dest += 7;
	}
}

// creates a snapshot of the OBD PID responses as a string, that is ready to be served over http
void report_obd_data()
{
	// store timestamp and battery voltage
	obd_result.MSG_TIMESTAMP = millis();
	obd_result.VBATT_MV = read_vcc_mv();

	// generate stringified buffer to deliver over http
	uint8_t *obd_result_as_bytes = reinterpret_cast<uint8_t *>(&obd_result);
	for (int i = 0; i < sizeof(obd_result); i++)
	{
		write_nibble(&result_buffer_text[i * 2], (obd_result_as_bytes[i] >> 4));
		write_nibble(&result_buffer_text[i * 2 + 1], (obd_result_as_bytes[i] & 0xF));
	}

	// null-terminate text buffer
	result_buffer_text[sizeof(result_buffer_text) - 1] = 0;

	// dump result into serial for debugging
	USBSerial.write(result_buffer_text, sizeof(result_buffer_text) - 1);
	USBSerial.println();
}

// runs in a loop indefinitely
void loop()
{
	// process incoming DNS requests
	dns_server.processNextRequest();

	// check the CAN inbox, and try to assemble any ISO-TP messages
	poll_transport();

	// sends a pid request. this delay could be further shortened, though 100ms seems to work
	if ((millis() - last_query_ms) > 100)
	{
		last_query_ms = millis();

		// sends a obd read request
		send_read_query(parameters_to_read[parameter_request_index]);

		// increment the parameter index to send a different parameter on the next loop
		parameter_request_index++;
		parameter_request_index %= PARAMETER_COUNT;

		// if a cycle is complete, snapshot the received data
		if (parameter_request_index == 0)
		{
			report_obd_data();
		}
	}
}

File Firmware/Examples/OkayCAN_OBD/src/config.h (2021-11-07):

#ifndef __OKAYCAN_CONFIG__
#define __OKAYCAN_CONFIG__

// OkayCAN pin definition
#define GPIO_CAN_RX GPIO_NUM_4
#define GPIO_CAN_TX GPIO_NUM_5
#define GPIO_VSENSE GPIO_NUM_2
#define GPIO_LED GPIO_NUM_16 // absent in V1.0

// Buffer sizes
#define MAX_TRANSACTION_SIZE (4128)

/* Max number of messages the receiver can receive at one time, this value 
 * is affected by can driver queue length
 */
static int ISO_TP_DEFAULT_BLOCK_SIZE = 8;

/* The STmin parameter value specifies the minimum time gap allowed between 
 * the transmission of consecutive frame network protocol data units
 */
static int ISO_TP_DEFAULT_ST_MIN = 0;

/* This parameter indicate how many FC N_PDU WTs can be transmitted by the 
 * receiver in a row.
 */
static int ISO_TP_MAX_WFT_NUMBER = 1;

/* Private: The default timeout to use when waiting for a response during a
 * multi-frame send or receive.
 */
static int ISO_TP_DEFAULT_RESPONSE_TIMEOUT = 1000;

/* Private: Determines if by default, padding is added to ISO-TP message frames.
 */
static int ISO_TP_FRAME_PADDING = 1;

/* CAN/TWAI controller data rate */
static int CAN_DATA_RATE = 500E3;

/* CAN/TWAI outbound arbitration id */
static int CAN_REQUEST_ID = 0x7E0; // ecu
// static int CAN_REQUEST_ID = 0x7DF; // broadcast (officially, obd uses a broadcast address)

/* CAN/TWAI inbound (filtered) arbitration id */
static int CAN_RESPONSE_ID = 0x7E8;

#endif

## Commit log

2021-11-01 Initial commit
    Snapshot of V1 board (fabbed)
    [OkayCAN.kicad_pcb, OkayCAN.sch, OkayCAN_BOM.csv]
2021-11-03 Add price breakdown
    For approximating cost per device
    [OkayCAN_Price_Breakdown.csv]
2021-11-07 Add V1.1
    [OkayCAN.kicad_pcb, OkayCAN.sch, OkayCAN_BOM.csv]
